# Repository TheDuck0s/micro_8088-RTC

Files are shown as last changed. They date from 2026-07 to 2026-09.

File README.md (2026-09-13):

# Micro 8088 + RTC

This is an IBM XT-compatible CPU and RTC card, based on a design by [Sergey Kiselev](https://github.com/skiselev) and [Aitor Gómez García](https://github.com/spark2k06).

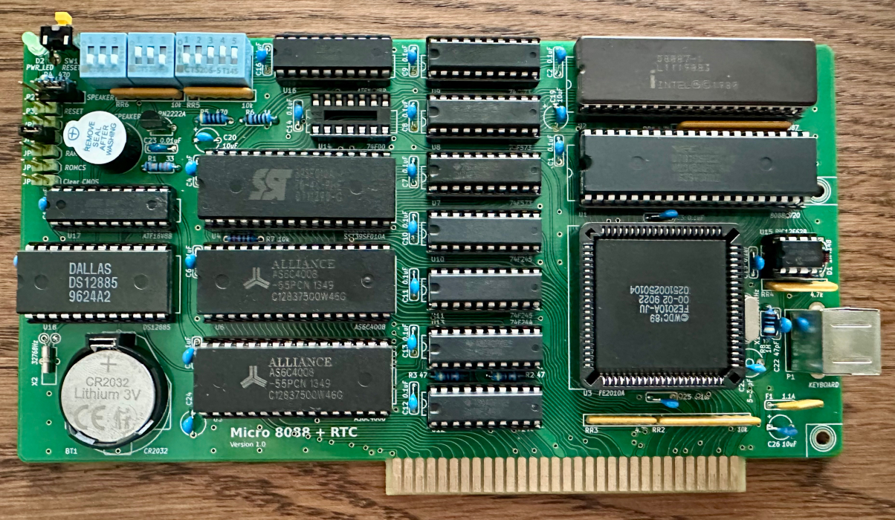
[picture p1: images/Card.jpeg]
Assembled Board 1.0


# The Idea

The goal of this project is to create an XT-compatible computer on a passive backplane with a modular card-based architecture, minimizing the overall footprint while providing support for all common expansion cards.

# Hardware Documentation
Schematic PDF:
[Schematic - Version 1.0](Micro_8088-RTC_Schematic.pdf)

PCB PDF:
[Board Design - Version 1.0](Micro_8088-RTC_Board_Design.pdf)

Gerber Files:
[Gerber- Version 1.0](gerber/)

SPLD:

* U16 CPU-Part:
[Use the repository provided by Sergey Kiselev](https://github.com/skiselev/micro_8088/tree/master/SPLD)

* U17 RTC-Part:
[Use the repository provided by Sergey Kiselev](https://github.com/skiselev/RTC8088/tree/main/SPLD)

AT2XT Firmware:
* U15 [minuszerodegrees.net](http://minuszerodegrees.net/at2xtkb/XTATKEY_094.zip)

# Bill of Materials

Component type    	| Reference | Description                       | Quantity 
------------------ | --------- | --------------------------------- | -------- 
PCB                |           | Micro 8080 + RTC PCB              | 1        
Integrated Circuit | U1        | Intel 8088, 80C88, or NEC V20 CPU | 1        
Integrated Circuit | U2        | Intel 8087 FPU                    | 1        
Integrated Circuit | U3        | Faraday FE2010A                   | 1        
Integrated Circuit | U4        | SST39SF010A Flash ROM, DIP-32 package | 1    
Integrated Circuit | U5, U6    | AS6C4008 SRAM, DIP-32 package     | 2        
Integrated Circuit | U7 - U9   | 74F573 Octal D-Type Latch         | 3        
Integrated Circuit | U10, U11  | 74F245 Octal Bus Transceiver      | 2        
Integrated Circuit | U12, U13  | 74F244 Octal Buffer               | 2        
Integrated Circuit | U14       | 74F00 Quad 2-Input NAND Gate      | 1        
Integrated Circuit | U15       | PIC12F629 Microcontroller         | 1        
Integrated Circuit | U16       | ATF16V8B SPLD                     | 1        
IC Socket          | U1, U2    | DIP-40, 600 mil socket            | 2        
IC Socket          | U3        | PLCC-84 through hole socket       | 1        
IC Socket          | U4-U6     | DIP-32, 600 mil socket            | 3        
IC Socket          | U7-U13, U16, U17 | DIP-20, 300 mil socket     | 9        
IC Socket          | U14       | DIP-14, 300 mil socket            | 1        
IC Socket          | U15       | DIP-8, 300 mil socket             | 1        
IC Socket          | U18       | DIP-24, 600 mil socket            | 1
Diode              | D1        | 1N4148                            | 1        
LED                | D2        | 3 mm, green LED indicator         | 1        
Transistor         | Q1        | PN2222A, 2.54mm lead spacing      | 1        
Crystal            | X1        | 28.63636 MHz, 18 pF, HC-49/S      | 1        
Crystal            | X2        | 32768Hz                           | 1
Battery            | BT1       | Battery socket                    | 1
Speaker            | SP1       | 12 mm speaker                     | 1        
Tactile Button     | SW1       | 6 mm tactile button, right angle  | 1        
DIP Switch         | SW2, SW3  | 3 positions                       | 2        
DIP Switch         | SW4       | 5 positions                       | 1        
Connector          | P1        | 6 pin Mini DIN, purple            | 1        
Pin Header         | P2        | 4 pin header, 2.54 mm pitch       | 1        
Pin Header         | P3, JP1-JP5 | 2 pin header, 2.54 mm pitch     | 6        
Capacitor          | C1 - C18  | 0.1 uF, MLCC, 5 mm lead spacing   | 19       
Capacitor          | C18 - C20 | 10 uF, MLCC, 5 mm lead spacing    | 3        
Trimmer Capacitor  | C21       | 6.5-30 pF, 5 mm lead spacing      | 1        
Capacitor          | C22       | 47 pF, MLCC, 5 mm lead spacing    | 1        
Capacitor          | C23       | 0.01 uF, MLCC, 5 mm lead spacing  | 1        
Resistor Array     | RR1       | 4.7 k, bussed, 10 pin SIP         | 1        
Resistor Array     | RR2       | 10 k, bussed, 10 pin SIP          | 1        
Resistor Array     | RR3, RR4  | 4.7 k, bussed, 6 pin SIP          | 2        
Resistor Array     | RR5, RR6  | 10 k, bussed, 6 pin SIP           | 2        
Resistor           | R1        | 33 ohm, through hole              | 1        
Resistor           | R2, R3    | 47 ohm, through hole              | 2        
Resistor           | R4, R5    | 470 ohm, through hole             | 2        
Resistor           | R6        | 1 kohm, through hole              | 1        
Resistor           | R7        | 10 kohm, through hole             | 1        
Resistor           | R8        | 1 Mohm, through hole              | 1        
Fuse               | F1        | 1.1A polyfuse, 5.08 mm lead pitch | 1        
ISA Bracket        |           | Keystone Electronics 9202         | 1        
Screw              |           | 4-40 x 1/4" Screw                 | 2        

# Release Notes

### Changes:

#### Version 1.0

 * Initial Release

# Benchmarks
 * CPU: D70108HCZ-16
 * FPU: 8087-1

### Checkit 3.0 Benchmark:
#### @4.77 MHz
 * 414 Dhrystones (1.20x)
 * 126.9K Whetstones (19.23x)

#### @7.16 MHz
 * 618 Dhrystones (1.80x)
 * 191.3K Whetstones (28.97x)

#### @9.55 MHz
 * 837 Dhrystones (2.43x)
 * 267.7K Whetstones (40.56x)

# Final Note
 * Install either U14 or U16, not both together
 * The card is tested and works.
 * This card won't fit Sergey's case ([this one](https://github.com/skiselev/micro_8088_case)). The case will need to be enlarged.
 * Card size 185.3 mm x 102.9 mm

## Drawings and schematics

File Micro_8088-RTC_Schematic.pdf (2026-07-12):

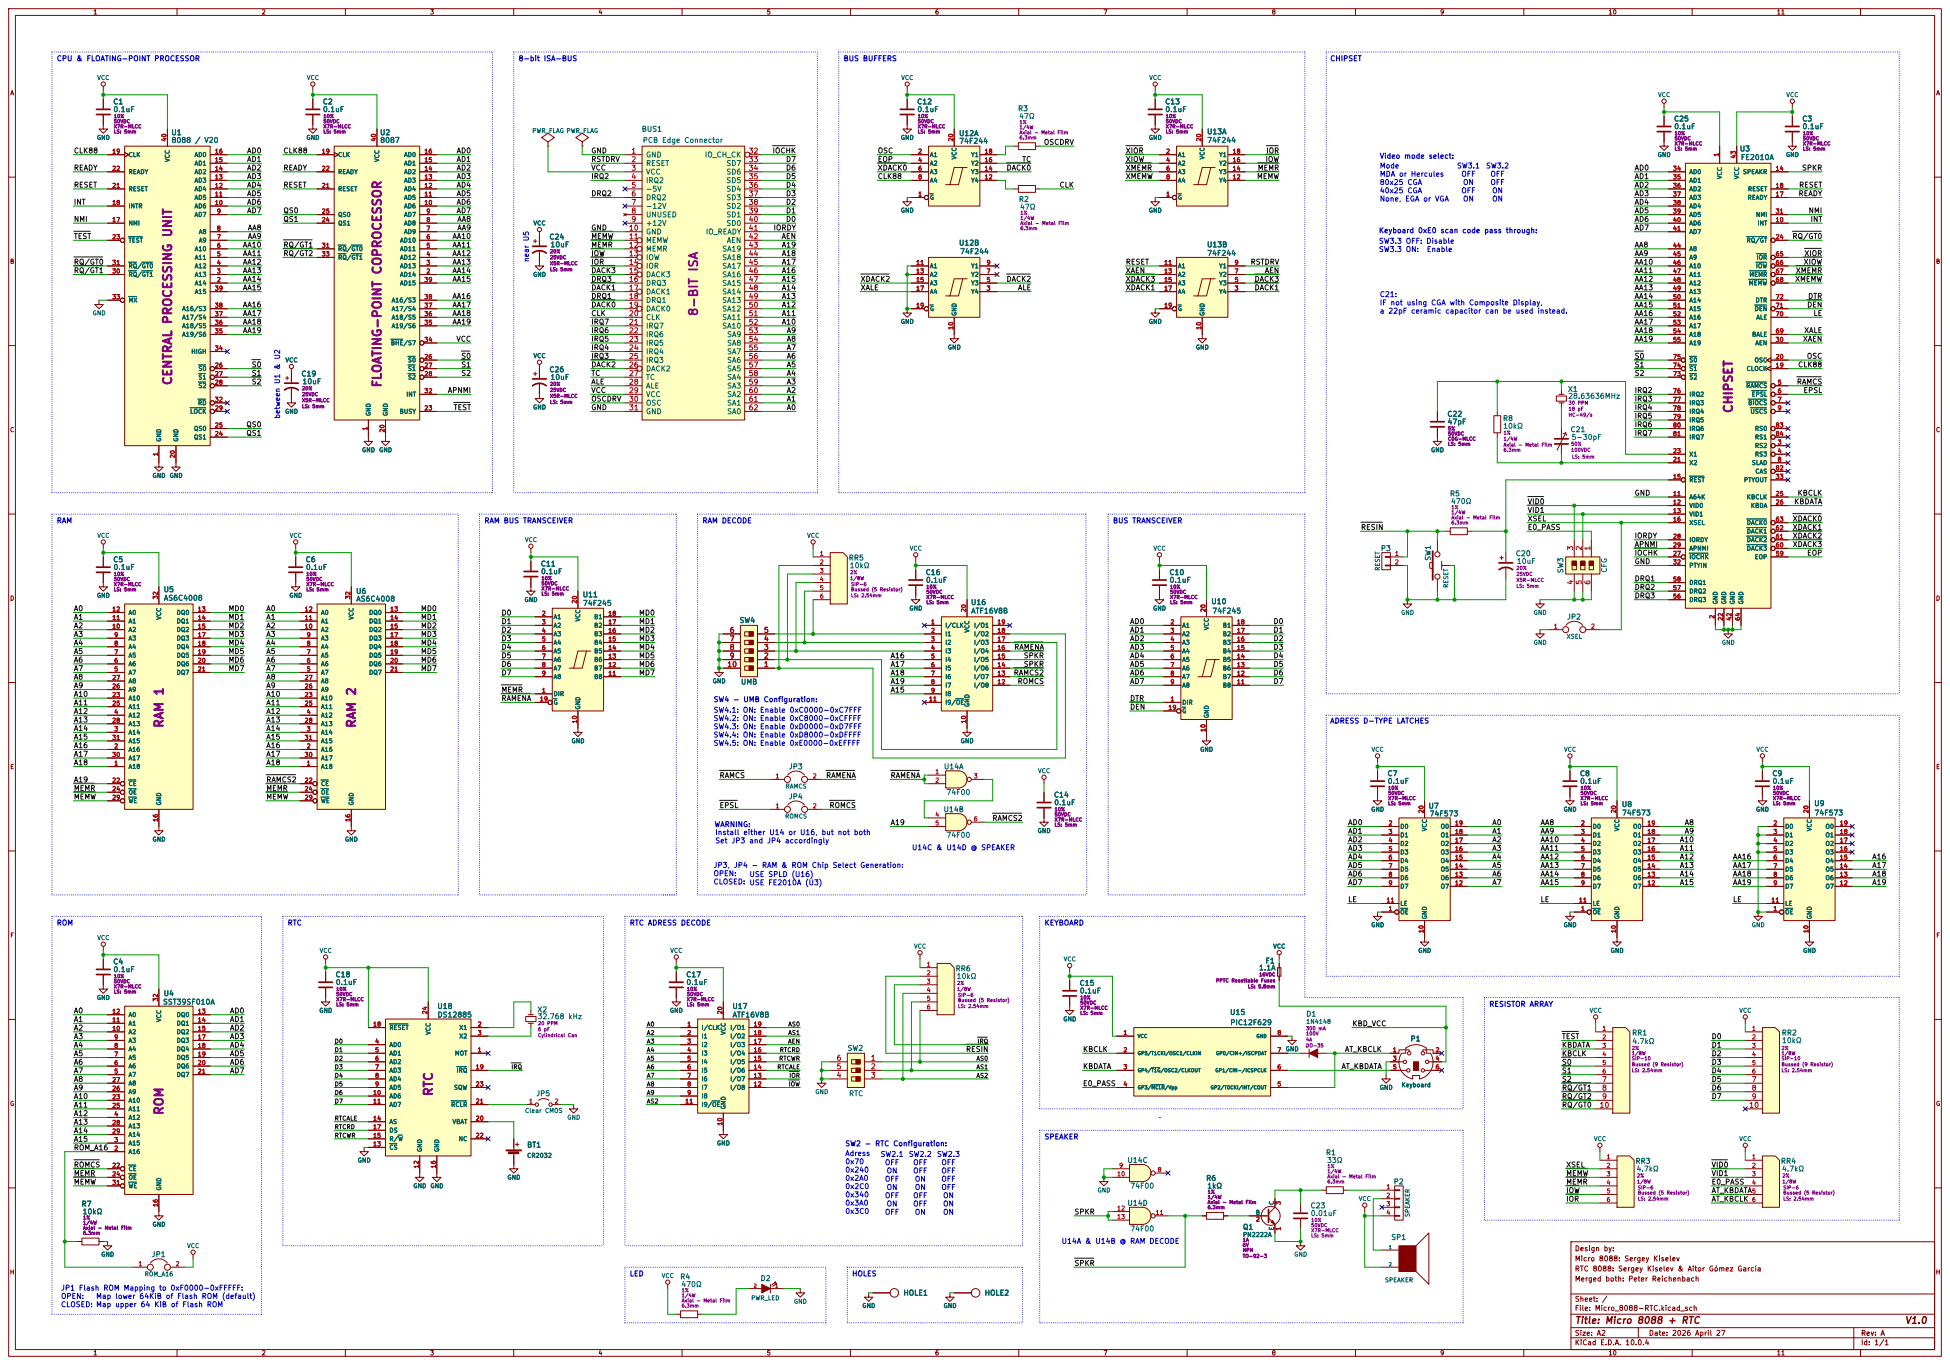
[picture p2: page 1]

8088 / V20 CENTRAL PROCESSING UNIT GND

8087 FLOATING-POINT COPROCESSOR GND

PCB Edge Connector 8-BIT ISA

None, EGA or VGA

Keyboard 0xE0 scan code pass through:
SW3.3 OFF: Disable
SW3.3 ON: Enable

IF not using CGA with Composite Display, a 22pF ceramic capacitor can be used instead.

GND GND 10 VCC 20 DIR

WARNING:
Install either U14 or U16, but not both
Set JP3 and JP4 accordingly

JP3, JP4 - RAM & ROM Chip Select Generation:
OPEN:
CLOSED:

Design by:
Micro 8088: Sergey Kiselev
RTC 8088: Sergey Kiselev & Aitor Gómez García
Merged both: Peter Reichenbach

JP1 Flash ROM Mapping to 0xF0000-0xFFFFF:

Map lower 64KiB of Flash ROM (default)
Map upper 64 KiB of Flash ROM

Size: A2 | Rev: A
KiCad E.D.A. 10.0.4 | Id: 1/1

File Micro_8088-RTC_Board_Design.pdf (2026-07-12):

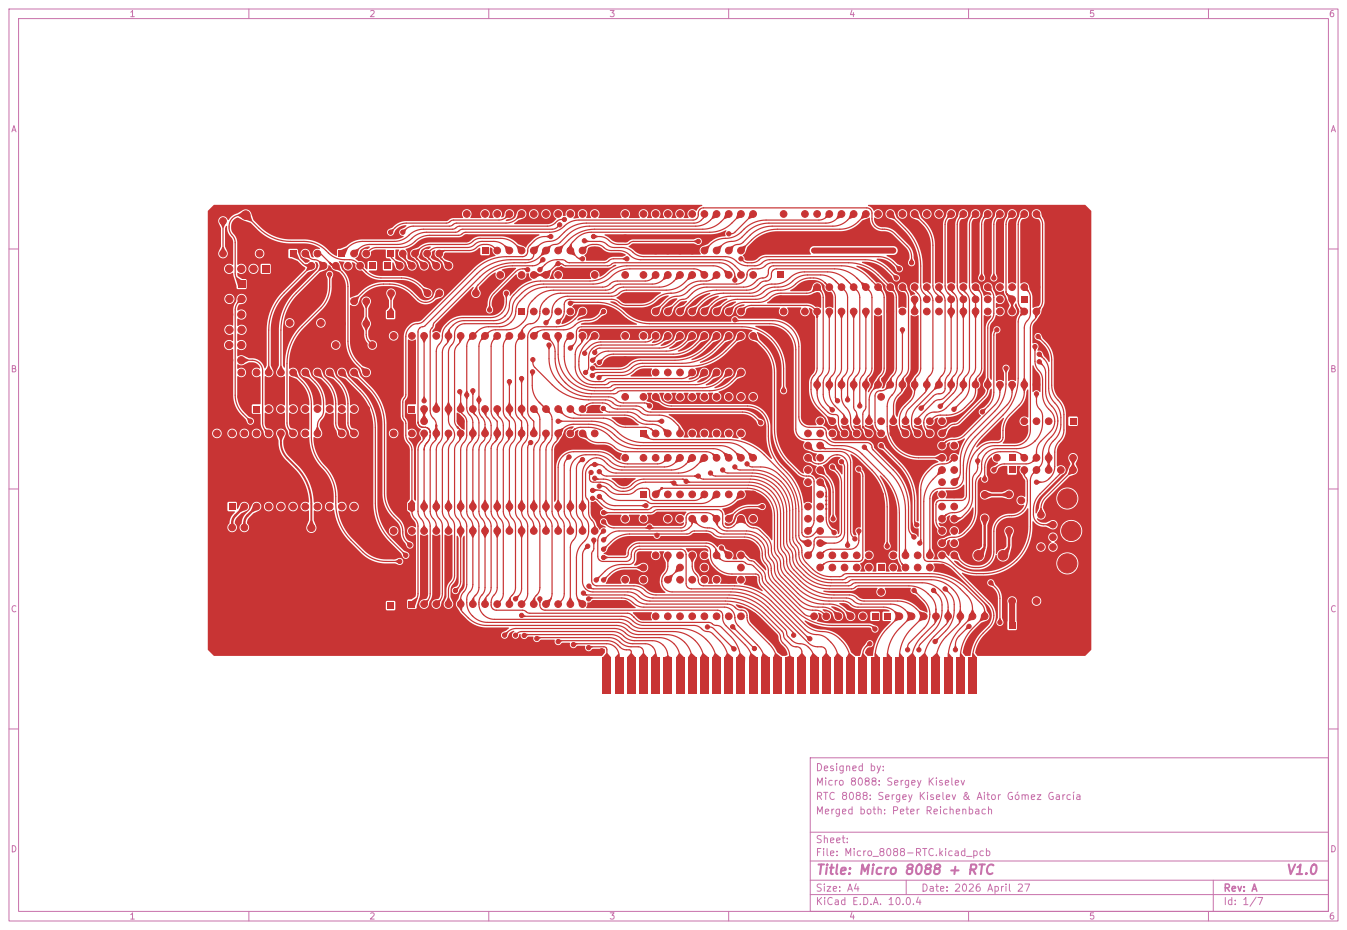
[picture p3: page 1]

Designed by:
Micro 8088: Sergey Kiselev
RTC 8088: Sergey Kiselev & Aitor Gómez García
Merged both: Peter Reichenbach

Size: A4 | Rev: A
KiCad E.D.A. 10.0.4 | Id: 1/7

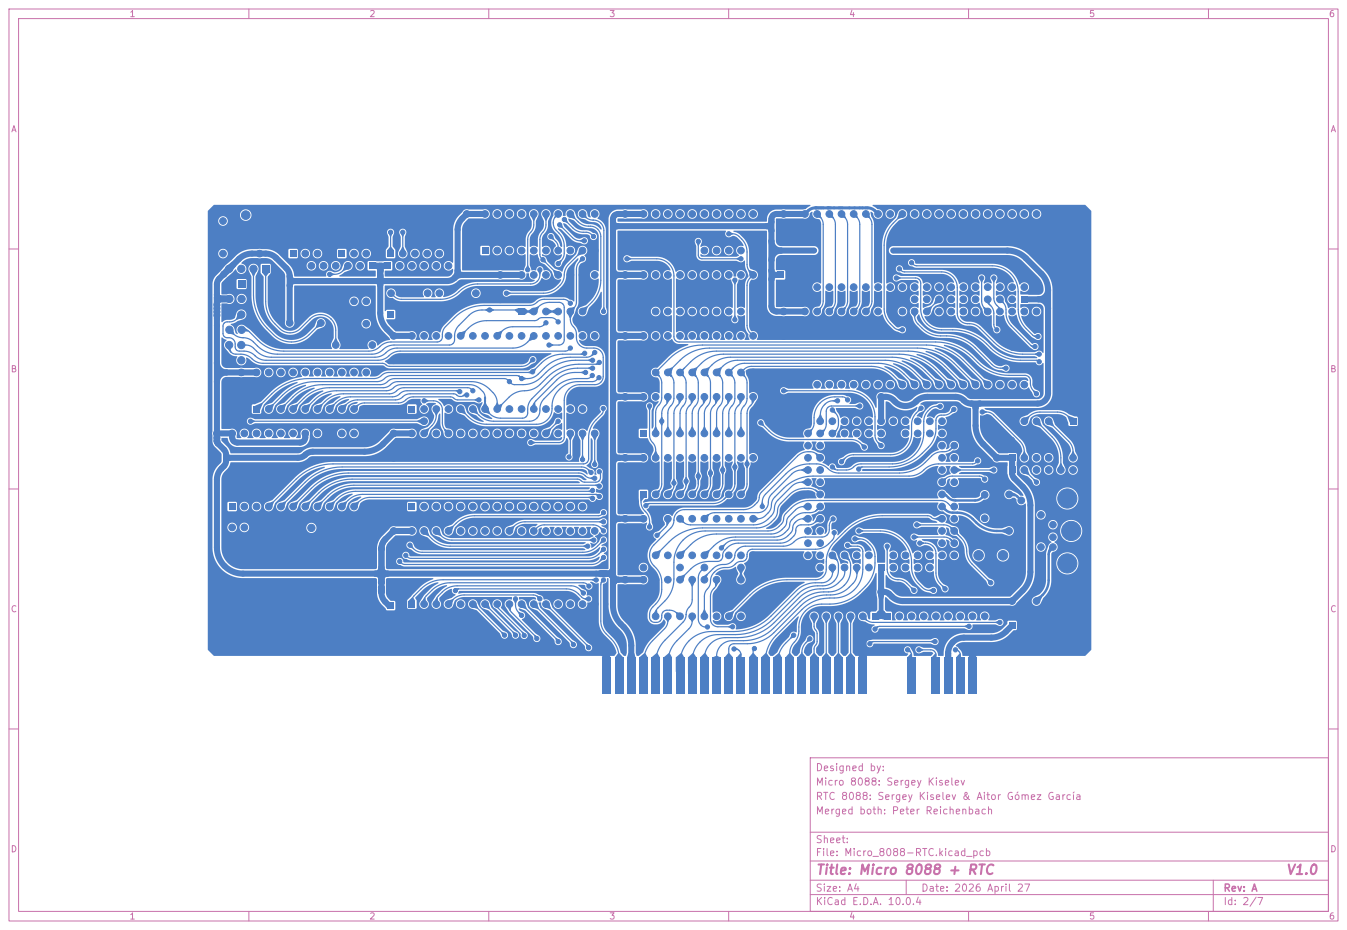
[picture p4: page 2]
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

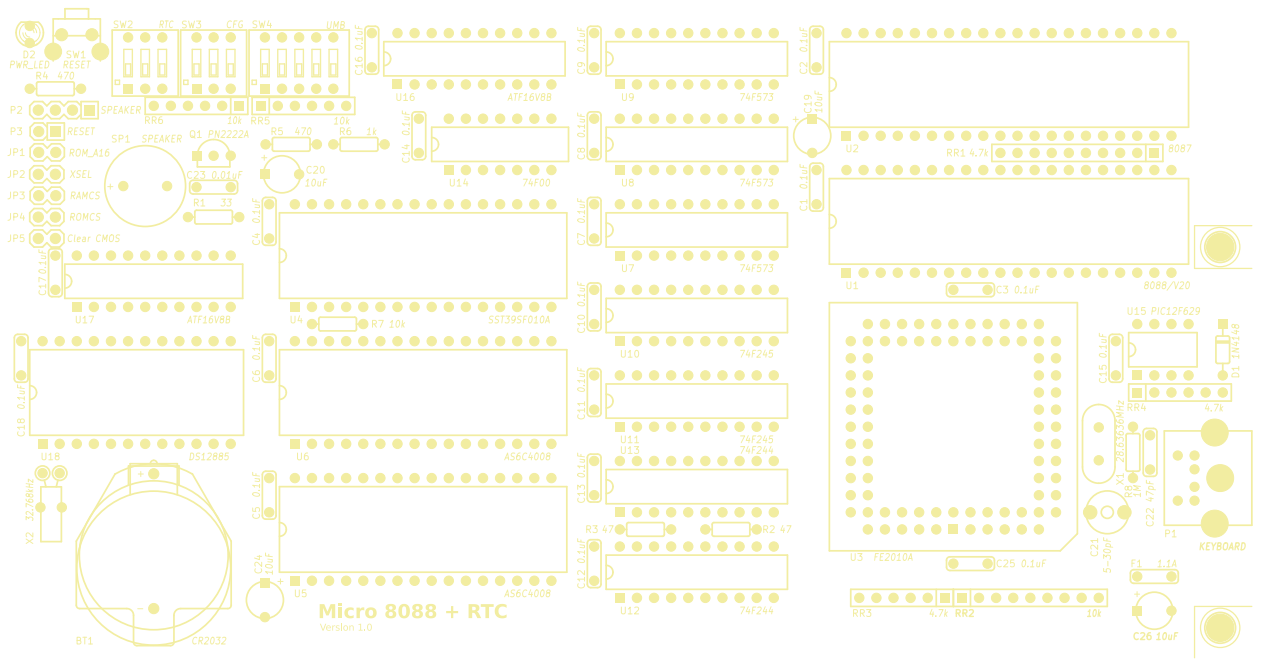
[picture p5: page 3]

Micro 8088: Sergey Kiselev
RTC 8088: Sergey Kiselev & Aitor Gómez García
Merged both: Peter Reichenbach

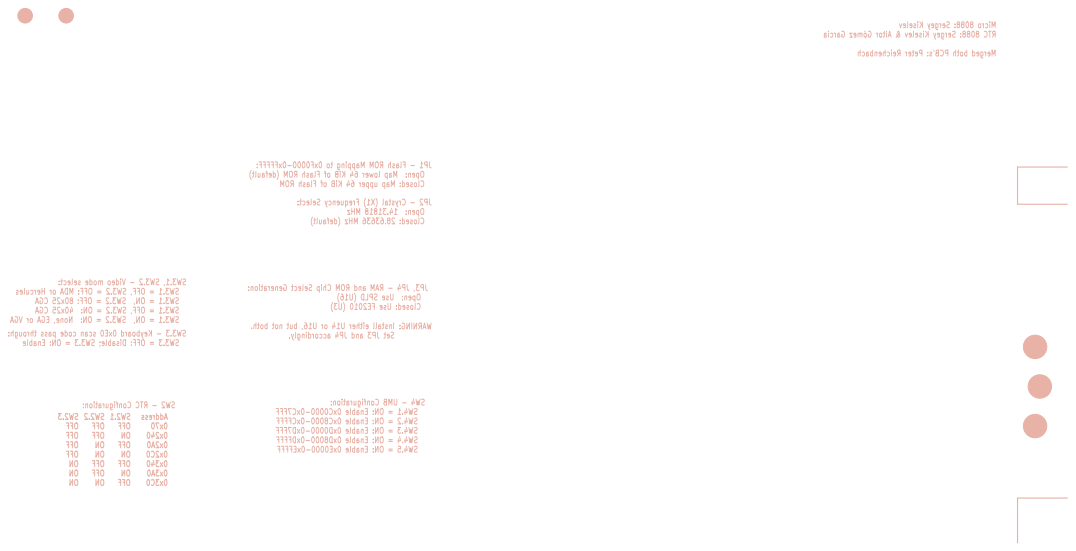
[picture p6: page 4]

Micro 8088: Sergey Kiselev
RTC 8088: Sergey Kiselev & Aitor Gómez García
Merged both: Peter Reichenbach

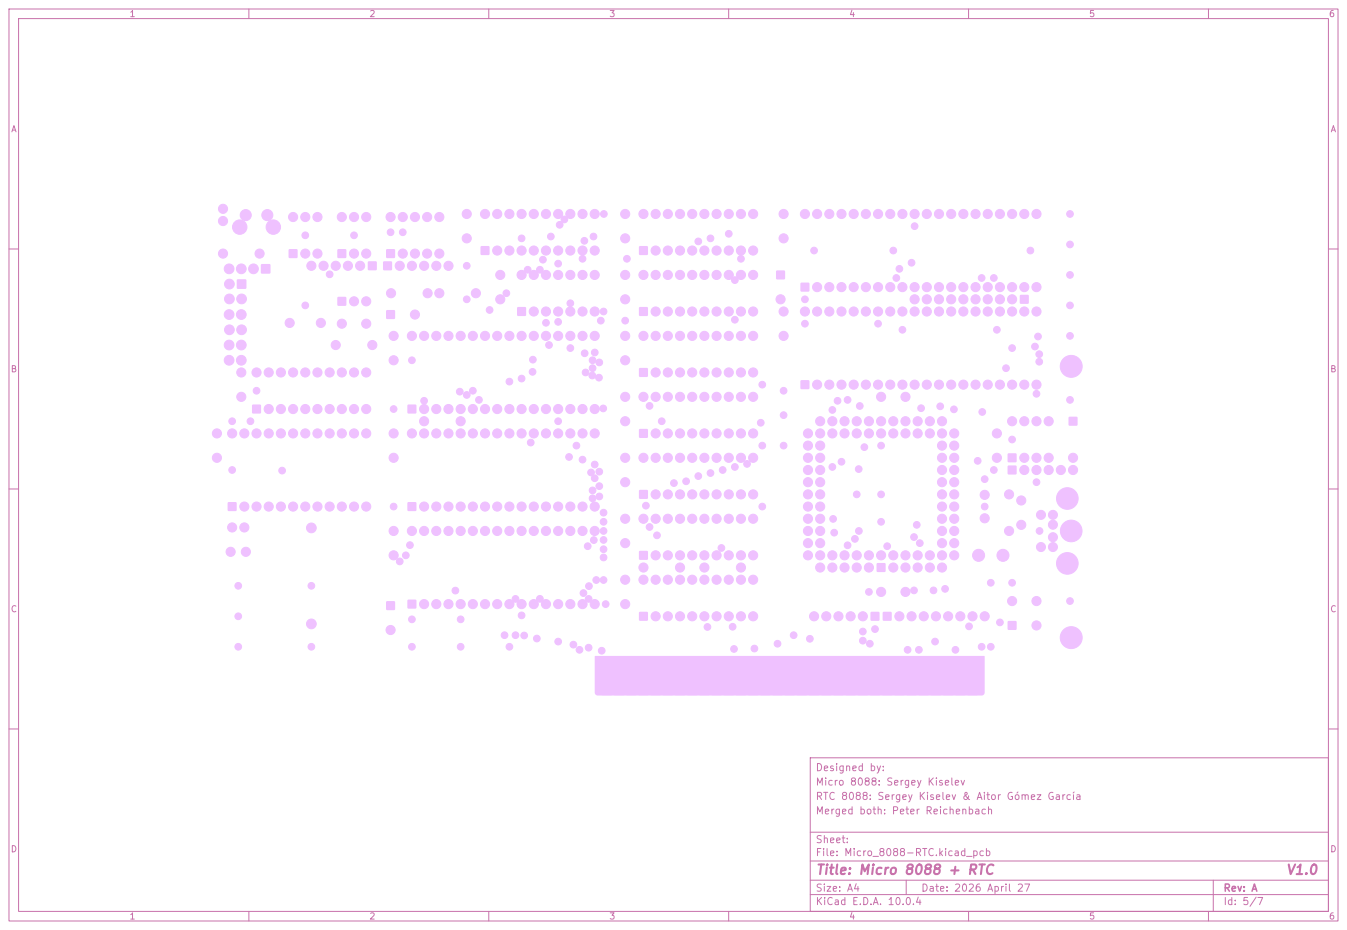
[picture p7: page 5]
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

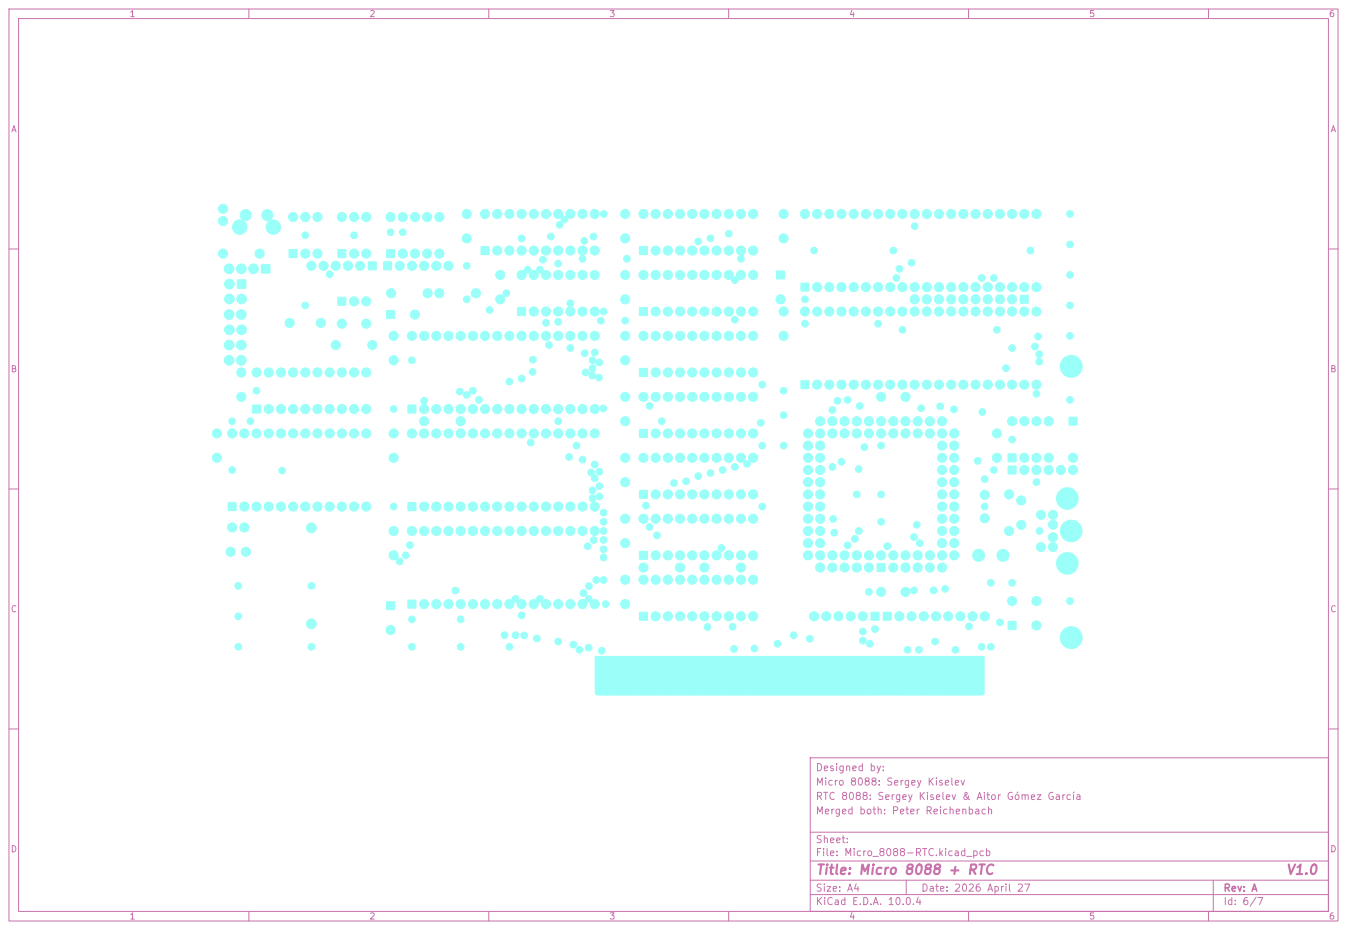
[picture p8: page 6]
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

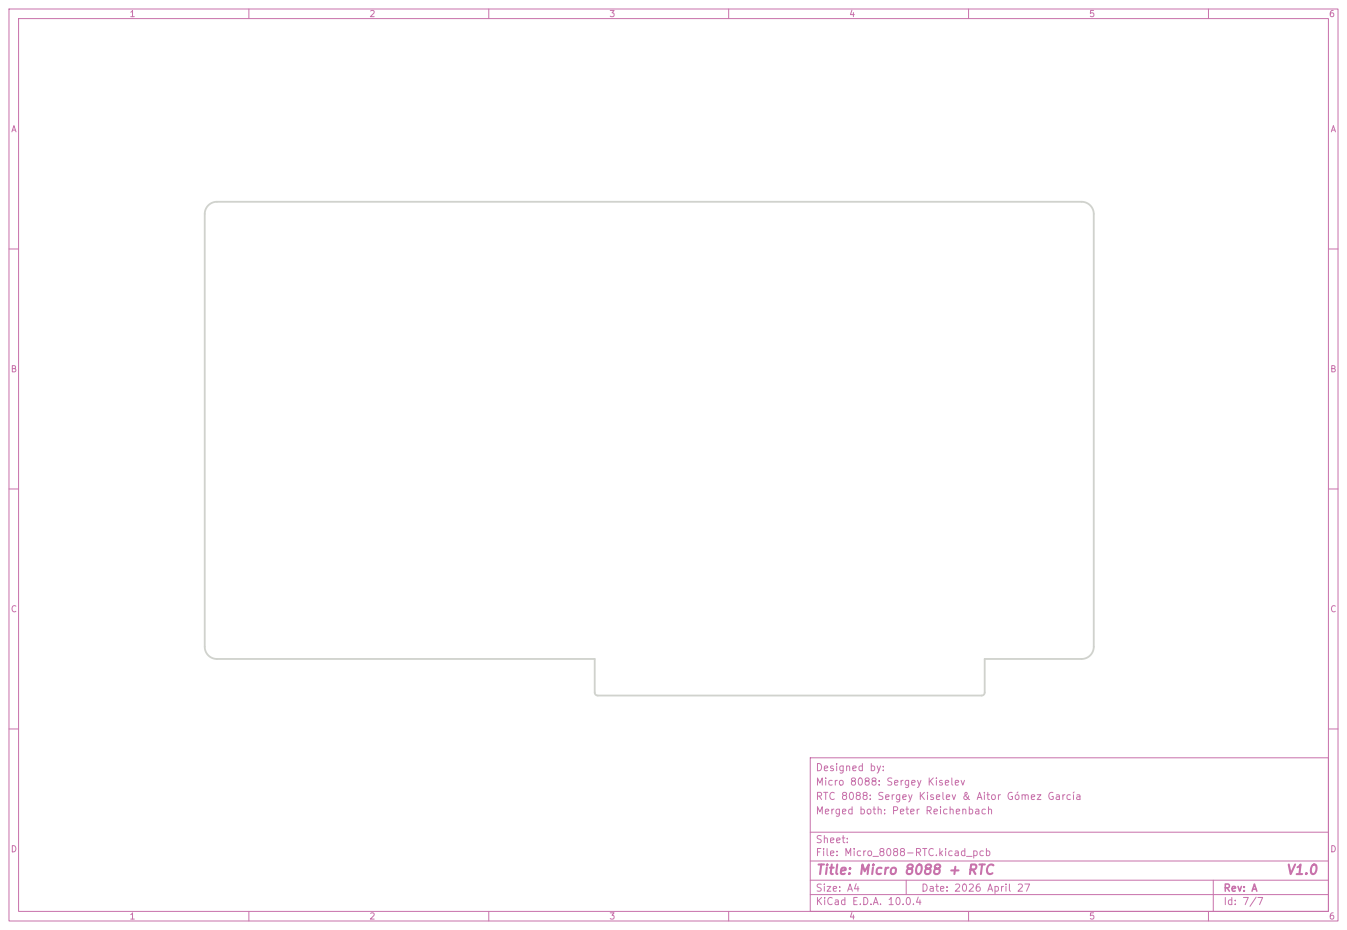
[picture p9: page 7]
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

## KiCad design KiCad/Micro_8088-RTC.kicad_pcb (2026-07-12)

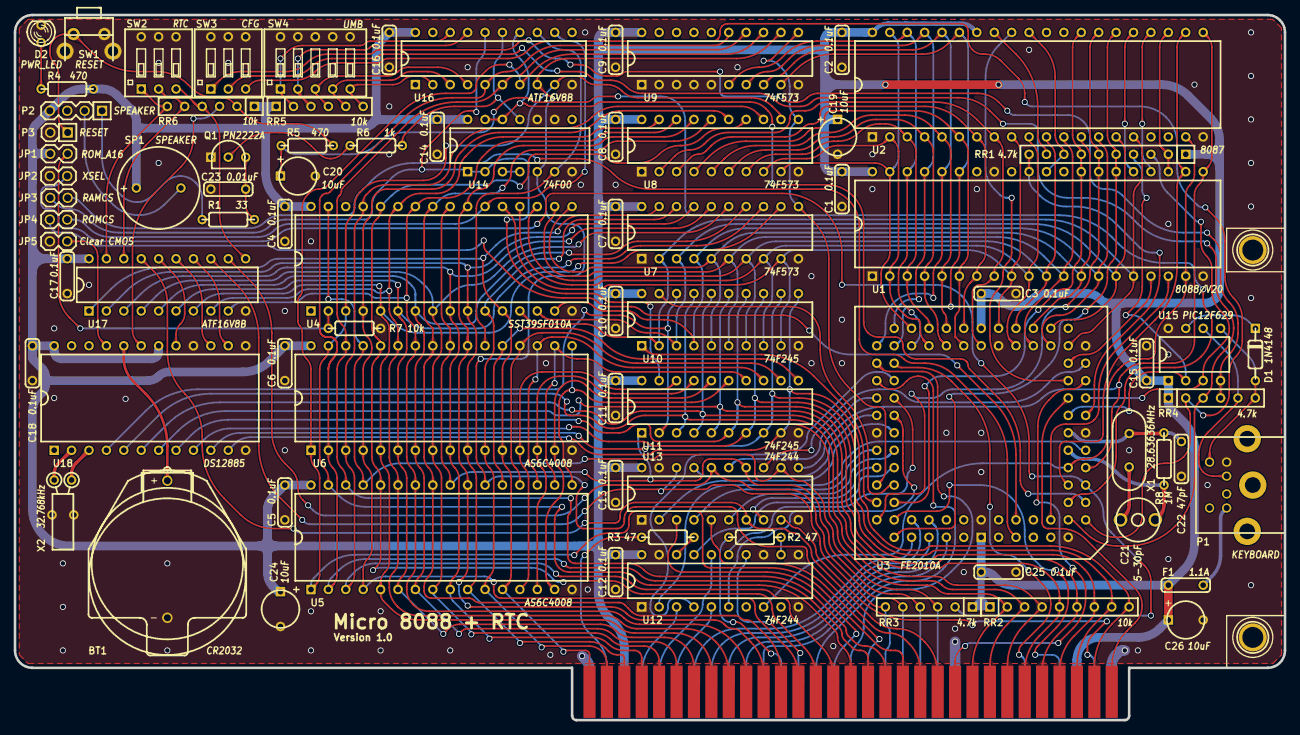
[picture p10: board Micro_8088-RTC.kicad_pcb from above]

Board: 2 copper layers, 185.3 x 102.9 mm, 81 parts (0 on the bottom side), 160 nets.

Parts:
BT1: CR2032; Battery_Holder_CR2032_Universal
BUS1: BUSPC_HOST; Conn_Edge_PCB_ISA8
C1, C2, C3, C4, C5, C6, C7, C8, C9, C10, C11, C12, C13, C14, C15, C16, C17, C18, C25: 0.1uF; Cap_Cer_508
C19, C20, C24, C26: 10uF; Cap_Tant_508
C21: 5-30pF; C_Trim_Murata
C22: 47pF; Cap_Cer_508
C23: 0.01uF; Cap_Cer_508
D1: 1N4148; Diode_762
D2: PWR_LED; LED_3mm
F1: 1.1A; Cap_Cer_508
HOLE1, HOLE2: HOLE; Hole_3mm
JP1: ROM_A16; Conn_Pin_Header_2x1_2.54mm_NoKey
JP2: XSEL; Conn_Pin_Header_2x1_2.54mm_NoKey
JP3: RAMCS; Conn_Pin_Header_2x1_2.54mm_NoKey
JP4: ROMCS; Conn_Pin_Header_2x1_2.54mm_NoKey
JP5: Clear CMOS; Conn_Pin_Header_2x1_2.54mm_NoKey
P1: KEYBOARD; Conn_Mini_DIN_6pin
P2: SPEAKER; Conn_Pin_Header_4x1_2.54mm
P3: RESET; Conn_Pin_Header_2x1_2.54mm
Q1: PN2222A; Transistor_TO92_EBC_254
R1: 33; Res_762
R2, R3: 47; Res_762
R4, R5: 470; Res_762
R6: 1k; Res_762
R7: 10k; Res_762
R8: 1M; Res_762
RR1: 4.7k; Conn_SIL10
RR2: 10k; Conn_SIL9
RR3, RR4: 4.7k; Conn_SIL6
RR5, RR6: 10k; Conn_SIL6
SP1: SPEAKER; Speaker_12mm
SW1: RESET; Switch_Tactile_6mm_Right
SW2: RTC; Switch_DIP_3_Positions
SW3: CFG; Switch_DIP_3_Positions
SW4: UMB; Switch_DIP_5_Positions
U1: 8088/V20; IC_DIP40_600
U2: 8087; IC_DIP40_600
U3: FE2010A; IC_PLCC84_TH
U4: SST39SF010A; IC_DIP32_600
U5, U6: AS6C4008; IC_DIP32_600
U7, U8, U9: 74F573; IC_DIP20_300
U10, U11: 74F245; IC_DIP20_300
U12, U13: 74F244; IC_DIP20_300
U14: 74F00; IC_DIP14_300
U15: PIC12F629; IC_DIP8_300
U16, U17: ATF16V8B; IC_DIP20_300
U18: DS12885; IC_DIP24_600
X1: 28.63636MHz; Crystal_HC-49U_Vert
X2: 32.768kHz; Crystal_32K_Horiz

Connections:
/A0: BUS1.62 (SA0), U4.12 (A0), U5.12 (A0), U6.12 (A0), U7.19 (O0), U17.1 (I/CLK)
/A1: BUS1.61 (SA1), U4.11 (A1), U5.11 (A1), U6.11 (A1), U7.18 (O1)
/A2: BUS1.60 (SA2), U4.10 (A2), U5.10 (A2), U6.10 (A2), U7.17 (O2), U17.2 (I1)
/A3: BUS1.59 (SA3), U4.9 (A3), U5.9 (A3), U6.9 (A3), U7.16 (O3), U17.3 (I2)
/A4: BUS1.58 (SA4), U4.8 (A4), U5.8 (A4), U6.8 (A4), U7.15 (O4), U17.4 (I3)
/A5: BUS1.57 (SA5), U4.7 (A5), U5.7 (A5), U6.7 (A5), U7.14 (O5), U17.5 (I4)
/A6: BUS1.56 (SA6), U4.6 (A6), U5.6 (A6), U6.6 (A6), U7.13 (O6), U17.6 (I5)
/A7: BUS1.55 (SA7), U4.5 (A7), U5.5 (A7), U6.5 (A7), U7.12 (O7), U17.7 (I6)
/A8: BUS1.54 (SA8), U4.27 (A8), U5.27 (A8), U6.27 (A8), U8.19 (O0), U17.8 (I7)
/A9: BUS1.53 (SA9), U4.26 (A9), U5.26 (A9), U6.26 (A9), U8.18 (O1), U17.9 (I8)
/A10: BUS1.52 (SA10), U4.23 (A10), U5.23 (A10), U6.23 (A10), U8.17 (O2)
/A11: BUS1.51 (SA11), U4.25 (A11), U5.25 (A11), U6.25 (A11), U8.16 (O3)
/A12: BUS1.50 (SA12), U4.4 (A12), U5.4 (A12), U6.4 (A12), U8.15 (O4)
/A13: BUS1.49 (SA13), U4.28 (A13), U5.28 (A13), U6.28 (A13), U8.14 (O5)
/A14: BUS1.48 (SA14), U4.29 (A14), U5.3 (A14), U6.3 (A14), U8.13 (O6)
/A15: BUS1.47 (SA15), U4.3 (A15), U5.31 (A15), U6.31 (A15), U8.12 (O7), U16.9 (I8)
/A16: BUS1.46 (SA16), U5.2 (A16), U6.2 (A16), U9.15 (O4), U16.5 (I4)
/A17: BUS1.45 (SA17), U5.30 (A17), U6.30 (A17), U9.14 (O5), U16.6 (I5)
/A18: BUS1.44 (SA18), U5.1 (A18), U6.1 (A18), U9.13 (O6), U16.7 (I6)
/A19: BUS1.43 (SA19), U5.22 (~CE), U9.12 (O7), U14.5, U16.8 (I7)
/AA8: U1.8 (A8), U2.8 (AD8), U3.44 (A8), U8.2 (D0)
/AA9: U1.7 (A9), U2.7 (AD9), U3.45 (A9), U8.3 (D1)
/AA10: U1.6 (A10), U2.6 (AD10), U3.46 (A10), U8.4 (D2)
/AA11: U1.5 (A11), U2.5 (AD11), U3.47 (A11), U8.5 (D3)
/AA12: U1.4 (A12), U2.4 (AD12), U3.48 (A12), U8.6 (D4)
/AA13: U1.3 (A13), U2.3 (AD13), U3.49 (A13), U8.7 (D5)
/AA14: U1.2 (A14), U2.2 (AD14), U3.50 (A14), U8.8 (D6)
/AA15: U1.39 (A15), U2.39 (AD15), U3.51 (A15), U8.9 (D7)
/AA16: U1.38 (A16/S3), U2.38 (A16/S3), U3.52 (A16), U9.6 (D4)
/AA17: U1.37 (A17/S4), U2.37 (A17/S4), U3.53 (A17), U9.7 (D5)
/AA18: U1.36 (A18/S5), U2.36 (A18/S5), U3.54 (A18), U9.8 (D6)
/AA19: U1.35 (A19/S6), U2.35 (A19/S6), U3.55 (A19), U9.9 (D7)
/AD0: U1.16 (AD0), U2.16 (AD0), U3.34 (AD0), U4.13 (DQ0), U7.2 (D0), U10.2 (A1)
/AD1: U1.15 (AD1), U2.15 (AD1), U3.35 (AD1), U4.14 (DQ1), U7.3 (D1), U10.3 (A2)
/AD2: U1.14 (AD2), U2.14 (AD2), U3.36 (AD2), U4.15 (DQ2), U7.4 (D2), U10.4 (A3)
/AD3: U1.13 (AD3), U2.13 (AD3), U3.37 (AD3), U4.17 (DQ3), U7.5 (D3), U10.5 (A4)
/AD4: U1.12 (AD4), U2.12 (AD4), U3.38 (AD4), U4.18 (DQ4), U7.6 (D4), U10.6 (A5)
/AD5: U1.11 (AD5), U2.11 (AD5), U3.39 (AD5), U4.19 (DQ5), U7.7 (D5), U10.7 (A6)
/AD6: U1.10 (AD6), U2.10 (AD6), U3.40 (AD6), U4.20 (DQ6), U7.8 (D6), U10.8 (A7)
/AD7: U1.9 (AD7), U2.9 (AD7), U3.41 (AD7), U4.21 (DQ7), U7.9 (D7), U10.9 (A8)
/AEN: BUS1.42 (AEN), U13.7 (Y2), U17.17 (I/O3)
/ALE: BUS1.28 (ALE), U12.3 (Y4)
/APNMI: U2.32 (INT), U3.29 (APNMI)
/AS0: RR6.6, SW2.1, U17.19 (I/O1)
/AS1: RR6.5, SW2.2, U17.18 (I/O2)
/AS2: RR6.4, SW2.3, U17.11 (I9/~OE)
/AT_KBCLK: D1.2 (A), P1.5, RR4.6, U15.5 (GP2/T0CKI/INT/COUT)
/AT_KBDATA: P1.1, RR4.5, U15.6 (GP1/CIN-/ICSPCLK)
/CLK: BUS1.20 (CLK), R2.1
/CLK88: U1.19 (CLK), U2.19 (CLK), U3.19 (CLOCK), U12.8 (A4)
/D0: BUS1.40 (SD0), RR2.2, U10.18 (B1), U11.2 (A1), U18.4 (AD0)
/D1: BUS1.39 (SD1), RR2.3, U10.17 (B2), U11.3 (A2), U18.5 (AD1)
/D2: BUS1.38 (SD2), RR2.4, U10.16 (B3), U11.4 (A3), U18.6 (AD2)
/D3: BUS1.37 (SD3), RR2.5, U10.15 (B4), U11.5 (A4), U18.7 (AD3)
/D4: BUS1.36 (SD4), RR2.6, U10.14 (B5), U11.6 (A5), U18.8 (AD4)
/D5: BUS1.35 (SD5), RR2.7, U10.13 (B6), U11.7 (A6), U18.9 (AD5)
/D6: BUS1.34 (SD6), RR2.8, U10.12 (B7), U11.8 (A7), U18.10 (AD6)
/D7: BUS1.33 (SD7), RR2.9, U10.11 (B8), U11.9 (A8), U18.11 (AD7)
/DRQ1: BUS1.18 (DRQ1), U3.58 (DRQ1)
/DRQ2: BUS1.6 (DRQ2), U3.57 (DRQ2)
/DRQ3: BUS1.16 (DRQ3), U3.56 (DRQ3)
/DTR: U3.72 (DTR), U10.1 (DIR)
/E0_PASS: RR4.4, SW3.1, U15.4 (GP3/~MCLR/Vpp)
/EOP: U3.59 (EOP), U12.4 (A2)
/INT: U1.18 (INTR), U3.10 (INT)
/IORDY: BUS1.41 (IO_READY), U3.28 (IORDY)
/IRQ2: BUS1.4 (IRQ2), U3.76 (IRQ2)
/IRQ3: BUS1.25 (IRQ3), U3.77 (IRQ3)
/IRQ4: BUS1.24 (IRQ4), U3.78 (IRQ4)
/IRQ5: BUS1.23 (IRQ5), U3.79 (IRQ5)
/IRQ6: BUS1.22 (IRQ6), U3.80 (IRQ6)
/IRQ7: BUS1.21 (IRQ7), U3.81 (IRQ7)
/KBCLK: RR1.4, U3.25 (KBCLK), U15.2 (GP5/T1CKI/OSC1/CLKIN)
/KBDATA: RR1.3, U3.26 (KBDA), U15.3 (GP4/~T1G/OSC2/CLKOUT)
/KBD_VCC: F1.1, P1.4
/LE: U3.70 (ALE), U7.11 (LE), U8.11 (LE), U9.11 (LE)
/MD0: U5.13 (DQ0), U6.13 (DQ0), U11.18 (B1)
/MD1: U5.14 (DQ1), U6.14 (DQ1), U11.17 (B2)
/MD2: U5.15 (DQ2), U6.15 (DQ2), U11.16 (B3)
/MD3: U5.17 (DQ3), U6.17 (DQ3), U11.15 (B4)
/MD4: U5.18 (DQ4), U6.18 (DQ4), U11.14 (B5)
/MD5: U5.19 (DQ5), U6.19 (DQ5), U11.13 (B6)
/MD6: U5.20 (DQ6), U6.20 (DQ6), U11.12 (B7)
/MD7: U5.21 (DQ7), U6.21 (DQ7), U11.11 (B8)
/NMI: U1.17 (NMI), U3.31 (NMI)
/OSC: U3.20 (OSC), U12.2 (A1)
/OSCDRV: BUS1.30 (OSC), R3.1
/QS0: U1.25 (QS0), U2.25 (QS0)
/QS1: U1.24 (QS1), U2.24 (QS1)
/READY: U1.22 (READY), U2.22 (READY), U3.17 (READY)
/RESET: U1.21 (RESET), U2.21 (RESET), U3.18 (RESET), U13.11 (A1)
/ROM_A16: JP1.1, R7.2, U4.2 (A16)
/RSTDRV: BUS1.2 (RESET), U13.9 (Y1)
/RTCALE: U17.14 (I/O6), U18.14 (AS)
/RTCRD: U17.16 (I/O4), U18.17 (DS)
/RTCWR: U17.15 (I/O5), U18.15 (R/~W)
/SPKR: U3.14 (SPEAKR), U14.12, U14.13, U16.14 (I/O6)
/TC: BUS1.27 (TC), U12.16 (Y2)
/XAEN: U3.30 (AEN), U13.13 (A2)
/XALE: U3.69 (BALE), U12.17 (A4)
/XSEL: JP2.2, RR3.2, U3.16 (XSEL)
/~DACK0: BUS1.19 (DACK0), U12.14 (Y3)
/~DACK1: BUS1.17 (DACK1), U13.3 (Y4)
/~DACK2: BUS1.26 (DACK2), U12.5 (Y3)
/~DACK3: BUS1.15 (DACK3), U13.5 (Y3)
/~DEN: U3.71 (~DEN), U10.19 (~G)
/~EPSL: JP4.1, U3.6 (~EPSL)
/~IOCHK: BUS1.32 (IO_CH_CK), U3.27 (~IOCHK)
/~IOR: BUS1.14 (IOR), RR3.6, U13.18 (Y1), U17.13 (I/O7)
/~IOW: BUS1.13 (IOW), RR3.5, U13.16 (Y2), U17.12 (I/O8)
/~IRQ: RR6.3, U18.19 (~IRQ)
/~MEMR: BUS1.12 (MEMR), RR3.4, U4.24 (~OE), U5.24 (~OE), U6.24 (~OE), U11.1 (DIR), U13.14 (Y3)
/~MEMW: BUS1.11 (MEMW), RR3.3, U4.31 (~WE), U5.29 (~WE), U6.29 (~WE), U13.12 (Y4)
/~RAMCS2: U6.22 (~CE), U14.6, U16.13 (I/O7)
/~RAMCS: JP3.1, U3.5 (~RAMCS)
/~RAMENA: JP3.2, U11.19 (~G), U14.1, U14.2, U16.16 (I/O4)
/~RESIN: P3.1, R5.2, RR6.2, SW1.2
/~ROMCS: JP4.2, U4.22 (~CE), U16.12 (I/O8)
/~RQ/GT0: RR1.10, U1.31 (~RQ/~GT0), U3.24 (~RQ/GT)
/~RQ/GT1: RR1.8, U1.30 (~RQ/~GT1), U2.31 (~RQ/~GT0)
/~RQ/GT2: RR1.9, U2.33 (~RQ/~GT1)
/~S0: RR1.5, U1.26 (~S0), U2.26 (~S0), U3.75 (~S0)
/~S1: RR1.6, U1.27 (~S1), U2.27 (~S1), U3.74 (~S1)
/~S2: RR1.7, U1.28 (~S2), U2.28 (~S2), U3.73 (~S2)
/~SPKR: R6.2, U14.11, U16.15 (I/O5)
/~TEST: RR1.2, U1.23 (~TEST), U2.23 (BUSY)
/~VID0: RR4.2, SW3.3, U3.12 (VID0)
/~VID1: RR4.3, SW3.2, U3.13 (VID1)
/~XDACK0: U3.63 (~DACK0), U12.6 (A3)
/~XDACK1: U3.62 (~DACK1), U13.17 (A4)
/~XDACK2: U3.61 (~DACK2), U12.15 (A3)
/~XDACK3: U3.60 (~DACK3), U13.15 (A3)
/~XIOR: U3.65 (~IOR), U13.2 (A1)
/~XIOW: U3.66 (~IOW), U13.4 (A2)
/~XMEMR: U3.67 (~MEMR), U13.6 (A3)
/~XMEMW: U3.68 (~MEMW), U13.8 (A4)
GND: BT1.2 (-), BUS1.1 (GND), BUS1.10 (GND), BUS1.31 (GND), C1.2, C2.2, C3.2, C4.2, C5.2, C6.2, C7.2, C8.2, C9.2, C10.2, C11.2, C12.2, C13.2, C14.2, C15.2, C16.2, C17.2, C18.2, C19.2, C20.2, C22.2, C23.2, C24.2, C25.2, C26.2, D2.1 (K), HOLE1.1, HOLE2.1, JP2.1, JP5.2 (B), P1.3, P3.2, Q1.1 (E), R7.1, SW1.1, SW1.GND, SW2.4, SW2.5, SW2.6, SW3.4, SW3.5, SW3.6, SW4.6, SW4.7, SW4.8, SW4.9, SW4.10, U1.1 (GND), U1.20 (GND), U1.33 (~MX), U2.1 (GND), U2.20 (GND), U3.2 (GND), U3.11 (A64K), U3.22 (GND), U3.32 (PTYIN), U3.42 (GND), U3.64 (GND), U4.16 (GND), U5.16 (GND), U6.16 (GND), U7.1 (~OE), U7.10 (GND), U8.1 (~OE), U8.10 (GND), U9.1 (~OE), U9.2 (D0), U9.3 (D1), U9.4 (D2), U9.5 (D3), U9.10 (GND), U10.10 (GND), U11.10 (GND), U12.1 (~G), U12.10 (GND), U12.11 (A1), U12.13 (A2), U12.19 (~G), U13.1 (~G), U13.10 (GND), U13.19 (~G), U14.7 (GND), U14.9, U14.10, U15.8 (GND), U16.10 (GND), U17.10 (GND), U18.12 (GND), U18.13 (~CS), U18.16 (GND), X2.3
unnamed: BT1.1 (+), U18.20 (VBAT)
unnamed: C21.1, X1.1
unnamed: D1.1 (K), U15.7 (GP0/CIN+/ISCPDAT)
unnamed: D2.2 (A), R4.2
unnamed: JP5.1 (A), U18.21 (~RCLR)
unnamed: P2.1, R1.1
unnamed: P2.2, SP1.1
unnamed: Q1.2 (B), R6.1
unnamed: C23.1, Q1.3 (C), R1.2
unnamed: C22.1, R8.1, U3.23 (X1), X1.2
unnamed: C21.2, R8.2, U3.21 (X2)
unnamed: C20.1, R5.1, U3.15 (~REST)
unnamed: R3.2, U12.18 (Y1)
unnamed: R2.2, U12.12 (Y4)
unnamed: U14.3, U14.4
unnamed: RR5.6, SW4.5, U16.2 (I1)
unnamed: RR5.5, SW4.4, U16.3 (I2)
unnamed: RR5.4, SW4.3, U16.4 (I3)
unnamed: RR5.2, SW4.1, U16.18 (I/O2)
unnamed: RR5.3, SW4.2, U16.17 (I/O3)
unnamed: U18.2 (X1), X2.1
unnamed: U18.3 (X2), X2.2
VCC: BUS1.3 (VCC), BUS1.29 (VCC), C1.1, C2.1, C3.1, C4.1, C5.1, C6.1, C7.1, C8.1, C9.1, C10.1, C11.1, C12.1, C13.1, C14.1, C15.1, C16.1, C17.1, C18.1, C19.1, C24.1, C25.1, C26.1, F1.2, JP1.2, P2.4, R4.1, RR1.1 (COM), RR2.1 (COM), RR3.1 (COM), RR4.1 (COM), RR5.1 (COM), RR6.1 (COM), SP1.2, U1.40 (VCC), U2.34 (~BHE/S7), U2.40 (VCC), U3.1 (VCC), U3.43 (VCC), U4.32 (VCC), U5.32 (VCC), U6.32 (VCC), U7.20 (VCC), U8.20 (VCC), U9.20 (VCC), U10.20 (VCC), U11.20 (VCC), U12.20 (VCC), U13.20 (VCC), U14.14 (VCC), U15.1 (VCC), U16.20 (VCC), U17.20 (VCC), U18.18 (~RESET), U18.24 (VCC)
